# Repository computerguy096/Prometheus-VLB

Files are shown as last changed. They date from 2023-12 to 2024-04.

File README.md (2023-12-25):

# Prometheus VLB - an affordable way to get a fast video card for your VLB systems

This is an open source video card, designed to be used in systems with a VLB slot, like a 486 class machine. It's designed around the S3 Trio64V+ video chip (86C765), which can be found in many PCI video cards, as wel as separately.
As a bonus, this particular chip allows for a very easy implementation for the VL bus, with almost no support components required, even the RAMDAC is built into the chip.
The card was designed from scratch, using only the official datasheet and photos of an STB Powergraph 64 for a few visual references.

Prometheus VLB rev 1A PCBs

## Features

- S3 Trio64V+ (86C765) or S3 ViRGE (86C325)[^1] video chip, with a powerful and very compatible 2D core, perfect for most DOS games
- up to 2MB of fast page or EDO memory, with clearance for SOJ sockets
- configurable address range, with 32MB, 64MB and 1024MB as options
- simple design, built in RAMDAC, only requires a few extra parts
- fully configurable registers with pull-downs, allowing the tuning of various parameters like memory timings, etc.
- flexible EEPROM implementation, allows DIP28, DIP32, as well as PLCC32 footprints
- common VGA connector placement, allows reusability for many of the old metallic brackets
- small PCB, which does not extend below the card edge in the front, so it will not collide with keyboard controller chips on some boards

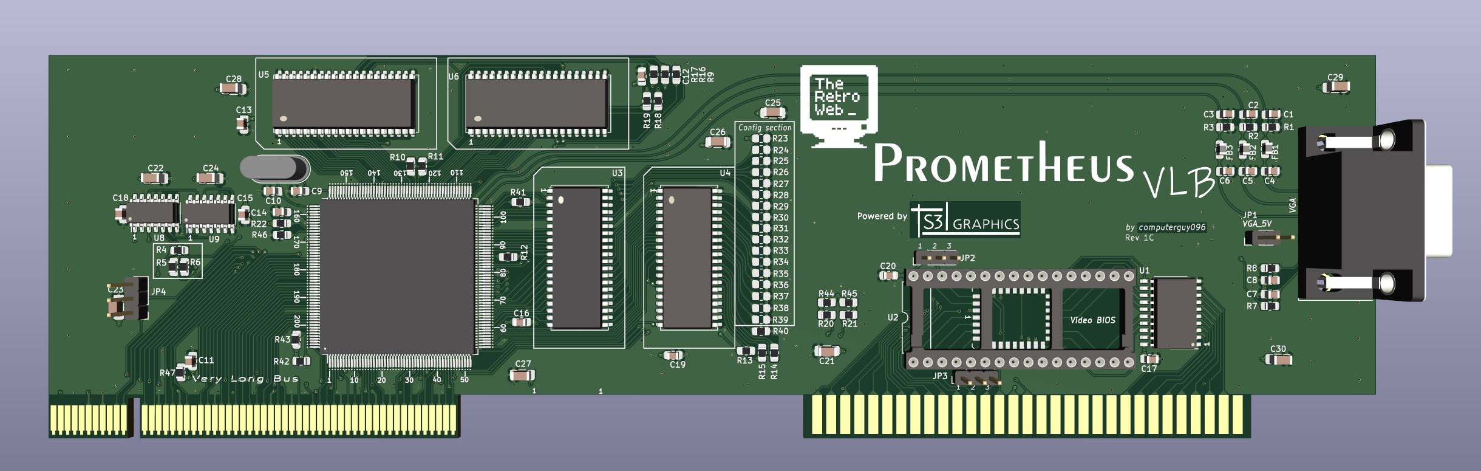
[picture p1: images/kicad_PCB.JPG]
Prometheus VLB rev 1B rendered PCB


## Documentation

Trio64V+ datasheet can be read [here](docs/DB018-A_Trio64V+_Integrated_Graphics_Video_Accelerator_Jul95.pdf), and the ViRGE datasheet [here](docs/DB019-B_ViRGE_Integrated_3D_Accelerator_Aug1996.pdf).

## FAQ

**Q: Is this for sale? Where can I buy one?**

> Nope, it's not for sale, and I do not have any intentions to sell them. However, I am an advocate for open source hardware so the design is fully public (the gerbers, the schematic, everything, all provided under GPLv3) so you can build your own card freely.

**Q: What parts do I need to build a card?**

> There is a [CSV BOM](kicad/virge-vlb.csv) included, as well as an [interactive HTML BOM](kicad/bom/ibom.html), with all the parts and their quantities listed. The main thing to acquire is the S3 chip itself, which can be salvaged from PCI cards or bought as NOS trays. 
**Be careful with the chip model, only 86C765 and 86C325 are fully pin compatible and will work!**

**Q: What about the video BIOS?**

> The binary is from an STB Powergraph64 (closest card to this one in terms of design) and it is available in the repository right [here](VBIOS.BIN)

**Q: Where can i find the gerber files?**

> At `/kicad/gerber` on this repo.

## Footnotes

[^1]: S3 ViRGE support is experimental in VLB mode, since there are no drivers available for it.

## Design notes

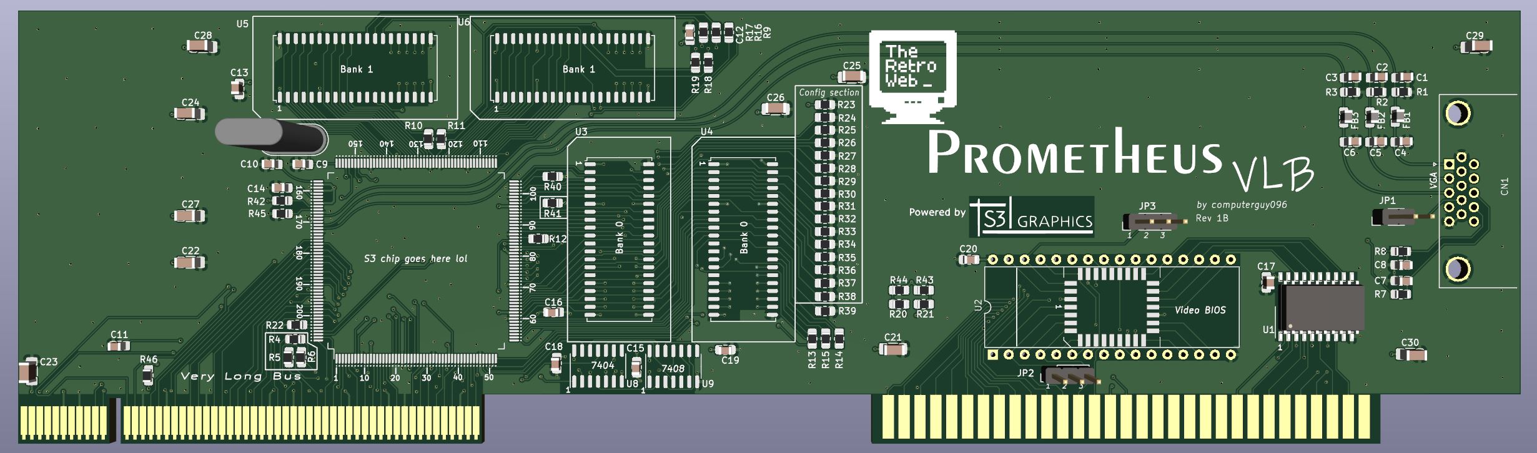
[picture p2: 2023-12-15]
images/rev1B.JPG

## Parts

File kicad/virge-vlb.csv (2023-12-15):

Component Count: | 93
Collated Components:
Item | Qty | Reference(s) | Value | LibPart | Footprint | Datasheet | DNP | Function | Installed | License | manf#
1 | 10 | C1, C2, C3, C4, C5, C6, C7, C8, C9, C10 | 10pF | Device:C | Capacitor_SMD:C_0805_2012Metric_Pad1.18x1.45mm_HandSolder | ~
2 | 1 | C11 | 100pF | Device:C | Capacitor_SMD:C_0805_2012Metric_Pad1.18x1.45mm_HandSolder | ~
3 | 9 | C12, C13, C14, C15, C16, C17, C18, C19, C20 | 100nF | Device:C | Capacitor_SMD:C_0805_2012Metric_Pad1.18x1.45mm_HandSolder | ~
4 | 10 | C21, C22, C23, C24, C25, C26, C27, C28, C29, C30 | 10uF | Device:C_Polarized | Capacitor_SMD:C_1206_3216Metric_Pad1.33x1.80mm_HandSolder | ~
5 | 1 | CN1 | VGA | Connector:DE15_Plug_HighDensity | VLB:DSUB-15_female | ~
6 | 3 | FB1, FB2, FB3 | FerriteBead | Device:FerriteBead | Inductor_SMD:L_0805_2012Metric_Pad1.15x1.40mm_HandSolder | ~
7 | 1 | JP1 | Conn_01x02 | Connector_Generic:Conn_01x02 | Connector_PinHeader_2.54mm:PinHeader_1x02_P2.54mm_Vertical | ~ |  | SPI Power DDC/i2c ROM
8 | 2 | JP2, JP3 | Conn_01x03 | Connector_Generic:Conn_01x03 | Connector_PinHeader_2.54mm:PinHeader_1x03_P2.54mm_Vertical | ~
9 | 15 | R1, R2, R9, R10, R11, R12, R13, R14, R15, R16, R17, R18, R19, R20, R21 | 33R | Device:R | Resistor_SMD:R_0805_2012Metric_Pad1.20x1.40mm_HandSolder | ~
10 | 3 | R3, R4, R5 | 75R | Device:R | Resistor_SMD:R_0805_2012Metric_Pad1.20x1.40mm_HandSolder | ~
11 | 3 | R6, R7, R8 | 0R | Device:R | Resistor_SMD:R_0805_2012Metric_Pad1.20x1.40mm_HandSolder | ~
12 | 23 | R22, R23, R24, R25, R26, R27, R28, R29, R30, R31, R32, R33, R34, R35, R36, R37, R38, R39, R40, R41, R42, R43, R44 | 10K | Device:R | Resistor_SMD:R_0805_2012Metric_Pad1.20x1.40mm_HandSolder | ~ |  |  | 1
13 | 2 | R45, R46 | 150R | Device:R | Resistor_SMD:R_0805_2012Metric_Pad1.20x1.40mm_HandSolder | ~
14 | 1 | U1 | 74LS244 | 74xx:74LS244 | Package_SO:SO-20_12.8x7.5mm_P1.27mm | http://www.ti.com/lit/ds/symlink/sn74ls244.pdf
15 | 1 | U2 | 27C020 | Memory_EPROM:27C020 | VLB:EEPROM_combo | http://ww1.microchip.com/downloads/en/devicedoc/doc0570.pdf
16 | 4 | U3, U4, U5, U6 | V53C16258H | :HY51V18164B_1 | VLB:SOJ-40_10.16x26.00mm_P1.27mm
17 | 1 | U7 | 86C325 | virge:86C375 | VLB:QFP-208 |  |  |  |  | 86C375 VL Bus | 86C375
18 | 1 | U8 | 7404 | 74xx:74HC04 | Package_SO:SO-14_3.9x8.65mm_P1.27mm | https://assets.nexperia.com/documents/data-sheet/74HC_HCT04.pdf
19 | 1 | U9 | 7408 | 74xx_IEEE:7408 | Package_SO:SO-14_3.9x8.65mm_P1.27mm
20 | 1 | Y1 | 14.318MHz | Device:Crystal | Crystal:Crystal_HC18-U_Vertical | ~

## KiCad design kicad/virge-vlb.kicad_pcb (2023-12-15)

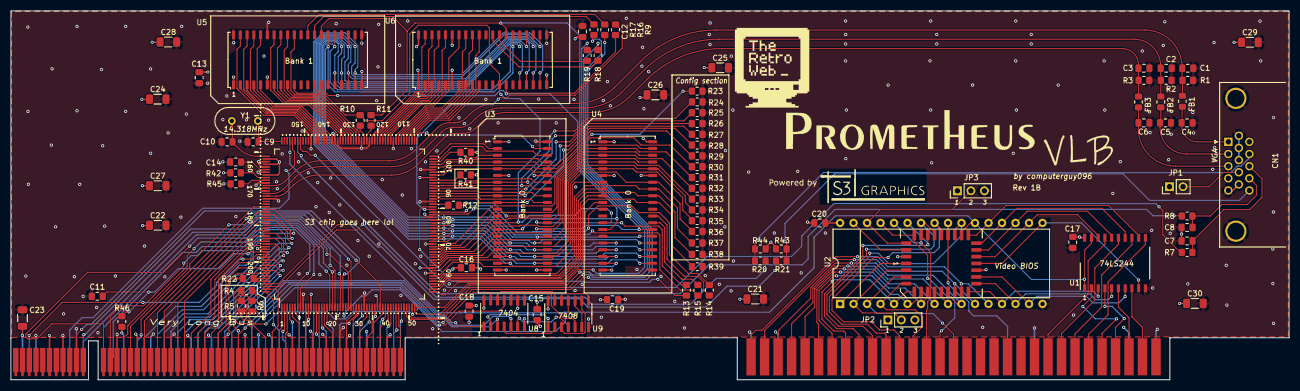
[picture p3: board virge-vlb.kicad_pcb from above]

Board: 4 copper layers, 240.5 x 69.4 mm, 94 parts (0 on the bottom side), 239 nets.

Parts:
C1, C2, C3, C4, C5, C6, C7, C8, C9, C10: 10pF; C_0805_2012Metric_Pad1.18x1.45mm_HandSolder
C11: 100pF; C_0805_2012Metric_Pad1.18x1.45mm_HandSolder
C12, C13, C14, C15, C16, C17, C18, C19, C20: 100nF; C_0805_2012Metric_Pad1.18x1.45mm_HandSolder
C21, C22, C23, C24, C25, C26, C27, C28, C29, C30: 10uF; C_1206_3216Metric_Pad1.33x1.80mm_HandSolder
CN1: VGA; DSUB-15_female
FB1, FB2, FB3: FerriteBead; L_0805_2012Metric_Pad1.15x1.40mm_HandSolder
J1: VLB_slot; BUS_VLB_Board
JP1: Conn_01x02; PinHeader_1x02_P2.54mm_Vertical
JP2, JP3: Conn_01x03; PinHeader_1x03_P2.54mm_Vertical
R1, R2, R3: 75R; R_0805_2012Metric_Pad1.20x1.40mm_HandSolder
R4, R5, R6: 0R; R_0805_2012Metric_Pad1.20x1.40mm_HandSolder
R7, R8, R9, R10, R11, R12, R13, R14, R15, R16, R17, R18, R19, R20, R21: 33R; R_0805_2012Metric_Pad1.20x1.40mm_HandSolder
R22, R23, R24, R25, R26, R27, R28, R29, R30, R31, R32, R33, R34, R35, R36, R37, R38, R39, R40, R41, R42, R43, R44: 10K; R_0805_2012Metric_Pad1.20x1.40mm_HandSolder
R45, R46: 150R; R_0805_2012Metric_Pad1.20x1.40mm_HandSolder
U1: 74LS244; SO-20_12.8x7.5mm_P1.27mm
U2: 27C020; EEPROM_combo
U3, U4, U5, U6: V53C16258H; SOJ-40_10.16x26.00mm_P1.27mm
U7: 86C325; QFP-208
U8: 7404; SO-14_3.9x8.65mm_P1.27mm
U9: 7408; SO-14_3.9x8.65mm_P1.27mm
Y1: 14.318MHz; Crystal_HC18-U_Vertical

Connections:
/BLUE: C6.1, CN1.3, FB3.1
/DDC_SCL: R21.1, U7.205 (SPCLK/ESYNC)
/DDC_SDA: R20.1, U7.206 (SPD/~BLANK)
/GREEN: C5.1, CN1.2, FB2.1
/HS: R7.1, U7.149 (HSYNC)
/HS_VGA: C7.1, CN1.13, R7.2
/ISA Bus/ISA_D0: J1.C40 (DB0), U1.17 (I3b)
/ISA Bus/ISA_D1: J1.C39 (DB1), U1.15 (I2b)
/ISA Bus/ISA_D2: J1.C38 (DB2), U1.13 (I1b)
/ISA Bus/ISA_D3: J1.C37 (DB3), U1.11 (I0b)
/ISA Bus/ISA_D4: J1.C36 (DB4), U1.2 (I0a)
/ISA Bus/ISA_D5: J1.C35 (DB5), U1.4 (I1a)
/ISA Bus/ISA_D6: J1.C34 (DB6), U1.6 (I2a)
/ISA Bus/ISA_D7: J1.C33 (DB7), U1.8 (I3a)
/ISA Bus/R_A0: J1.C62 (BA00), U2.12 (A0)
/ISA Bus/R_A1: J1.C61 (BA01), U2.11 (A1)
/ISA Bus/R_A2: J1.C60 (BA02), U2.10 (A2)
/ISA Bus/R_A3: J1.C59 (BA03), U2.9 (A3)
/ISA Bus/R_A4: J1.C58 (BA04), U2.8 (A4)
/ISA Bus/R_A5: J1.C57 (BA05), U2.7 (A5)
/ISA Bus/R_A6: J1.C56 (BA06), U2.6 (A6)
/ISA Bus/R_A7: J1.C55 (BA07), U2.5 (A7)
/ISA Bus/R_A8: J1.C54 (BA08), U2.27 (A8)
/ISA Bus/R_A9: J1.C53 (BA09), U2.26 (A9)
/ISA Bus/R_A10: J1.C52 (BA10), U2.23 (A10)
/ISA Bus/R_A11: J1.C51 (BA11), U2.25 (A11)
/ISA Bus/R_A12: J1.C50 (BA12), U2.4 (A12)
/ISA Bus/R_A13: J1.C49 (BA13), U2.28 (A13)
/ISA Bus/R_A14: J1.C48 (BA14), U2.29 (A14)
/ISA Bus/R_A15: J1.C47 (BA15), U2.3 (A15)
/ISA Bus/R_D0: U1.3 (O3b), U2.13 (D0)
/ISA Bus/R_D1: U1.5 (O2b), U2.14 (D1)
/ISA Bus/R_D2: U1.7 (O1b), U2.15 (D2)
/ISA Bus/R_D3: U1.9 (O0b), U2.17 (D3)
/ISA Bus/R_D4: U1.18 (O0a), U2.18 (D4)
/ISA Bus/R_D5: U1.16 (O1a), U2.19 (D5)
/ISA Bus/R_D6: U1.14 (O2a), U2.20 (D6)
/ISA Bus/R_D7: U1.12 (O3a), U2.21 (D7)
/ISA Bus/SMEMR: J1.C12 (~SMEMR), U2.24 (~OE)
/Memory Bus/CAS0: R12.2, U3.29 (~LCAS)
/Memory Bus/CAS1: R13.2, U3.28 (~UCAS)
/Memory Bus/CAS2: R14.2, U4.29 (~LCAS)
/Memory Bus/CAS3: R15.2, U4.28 (~UCAS)
/Memory Bus/CAS4: R16.2, U5.29 (~LCAS)
/Memory Bus/CAS5: R17.2, U5.28 (~UCAS)
/Memory Bus/CAS6: R18.2, U6.29 (~LCAS)
/Memory Bus/CAS7: R19.2, U6.28 (~UCAS)
/Memory Bus/MA0: U3.16 (A0), U4.16 (A0), U5.16 (A0), U6.16 (A0), U7.79 (MA0)
/Memory Bus/MA1: U3.17 (A1), U4.17 (A1), U5.17 (A1), U6.17 (A1), U7.77 (MA1)
/Memory Bus/MA2: U3.18 (A2), U4.18 (A2), U5.18 (A2), U6.18 (A2), U7.75 (MA2)
/Memory Bus/MA3: U3.19 (A3), U4.19 (A3), U5.19 (A3), U6.19 (A3), U7.73 (MA3)
/Memory Bus/MA4: U3.22 (A4), U4.22 (A4), U5.22 (A4), U6.22 (A4), U7.72 (MA4)
/Memory Bus/MA5: U3.23 (A5), U4.23 (A5), U5.23 (A5), U6.23 (A5), U7.74 (MA5)
/Memory Bus/MA6: U3.24 (A6), U4.24 (A6), U5.24 (A6), U6.24 (A6), U7.76 (MA6)
/Memory Bus/MA7: U3.25 (A7), U4.25 (A7), U5.25 (A7), U6.25 (A7), U7.78 (MA7)
/Memory Bus/MA8: U3.26 (A8), U4.26 (A8), U5.26 (A8), U6.26 (A8), U7.80 (MA8)
/Memory Bus/OE: R11.2, U3.27 (OE), U4.27 (OE), U5.27 (OE), U6.27 (OE)
/Memory Bus/PD0: U3.2 (DQ0), U7.104 (PD0)
/Memory Bus/PD1: R40.2, U3.3 (DQ1), U7.102 (PD1)
/Memory Bus/PD2: R29.2, U3.4 (DQ2), U7.100 (PD2)
/Memory Bus/PD3: R30.2, U3.5 (DQ3), U7.97 (PD3)
/Memory Bus/PD4: R25.2, U3.7 (DQ4), U7.94 (PD4)
/Memory Bus/PD5: R26.2, U3.8 (DQ5), U7.92 (PD5)
/Memory Bus/PD6: R27.2, U3.9 (DQ6), U7.90 (PD6)
/Memory Bus/PD7: R28.2, U3.10 (DQ7), U7.88 (PD7)
/Memory Bus/PD8: U3.31 (DQ8), U7.89 (PD8)
/Memory Bus/PD9: U3.32 (DQ9), U7.91 (PD9)
/Memory Bus/PD10: R24.2, U3.33 (DQ10), U7.93 (PD10)
/Memory Bus/PD11: R41.2, U3.34 (DQ11), U7.95 (PD11)
/Memory Bus/PD12: R23.2, U3.36 (DQ12), U7.98 (PD12)
/Memory Bus/PD13: U3.37 (DQ13), U7.101 (PD13)
/Memory Bus/PD14: U3.38 (DQ14), U7.103 (PD14)
/Memory Bus/PD15: U3.39 (DQ15), U7.105 (PD15)
/Memory Bus/PD16: R31.2, U4.2 (DQ0), U7.69 (PD16)
/Memory Bus/PD17: R32.2, U4.3 (DQ1), U7.67 (PD17)
/Memory Bus/PD18: R33.2, U4.4 (DQ2), U7.65 (PD18)
/Memory Bus/PD19: R35.2, U4.5 (DQ3), U7.63 (PD19)
/Memory Bus/PD20: U4.7 (DQ4), U7.59 (PD20)
/Memory Bus/PD21: U4.8 (DQ5), U7.57 (PD21)
/Memory Bus/PD22: U4.9 (DQ6), U7.55 (PD22)
/Memory Bus/PD23: U4.10 (DQ7), U7.53 (PD23)
/Memory Bus/PD24: R39.2, U4.31 (DQ8), U7.54 (PD24)
/Memory Bus/PD25: R38.2, U4.32 (DQ9), U7.56 (PD25)
/Memory Bus/PD26: R37.2, U4.33 (DQ10), U7.58 (PD26)
/Memory Bus/PD27: R36.2, U4.34 (DQ11), U7.61 (PD27)
/Memory Bus/PD28: R34.2, U4.36 (DQ12), U7.64 (PD28)
/Memory Bus/PD29: U4.37 (DQ13), U7.66 (PD29)
/Memory Bus/PD30: U4.38 (DQ14), U7.68 (PD30)
/Memory Bus/PD31: U4.39 (DQ15), U7.70 (PD31)
/Memory Bus/PD32: U5.2 (DQ0), U7.143 (PD32)
/Memory Bus/PD33: U5.3 (DQ1), U7.141 (PD33)
/Memory Bus/PD34: U5.4 (DQ2), U7.139 (PD34)
/Memory Bus/PD35: U5.5 (DQ3), U7.136 (PD35)
/Memory Bus/PD36: U5.7 (DQ4), U7.133 (PD36)
/Memory Bus/PD37: U5.8 (DQ5), U7.131 (PD37)
/Memory Bus/PD38: U5.9 (DQ6), U7.129 (PD38)
/Memory Bus/PD39: U5.10 (DQ7), U7.127 (PD39)
/Memory Bus/PD40: U5.31 (DQ8), U7.128 (PD40)
/Memory Bus/PD41: U5.32 (DQ9), U7.130 (PD41)
/Memory Bus/PD42: U5.33 (DQ10), U7.132 (PD42)
/Memory Bus/PD43: U5.34 (DQ11), U7.134 (PD43)
/Memory Bus/PD44: U5.36 (DQ12), U7.138 (PD44)
/Memory Bus/PD45: U5.37 (DQ13), U7.140 (PD45)
/Memory Bus/PD46: U5.38 (DQ14), U7.142 (PD46)
/Memory Bus/PD47: U5.39 (DQ15), U7.144 (PD47)
/Memory Bus/PD48: U6.2 (DQ0), U7.121 (PD48)
/Memory Bus/PD49: U6.3 (DQ1), U7.119 (PD49)
/Memory Bus/PD50: U6.4 (DQ2), U7.117 (PD50)
/Memory Bus/PD51: U6.5 (DQ3), U7.115 (PD51)
/Memory Bus/PD52: U6.7 (DQ4), U7.112 (PD52)
/Memory Bus/PD53: U6.8 (DQ5), U7.110 (PD53)
/Memory Bus/PD54: U6.9 (DQ6), U7.108 (PD54)
/Memory Bus/PD55: U6.10 (DQ7), U7.106 (VCLKI/PD55)
/Memory Bus/PD56: U6.31 (DQ8), U7.107 (PD56)
/Memory Bus/PD57: U6.32 (DQ9), U7.109 (PD57)
/Memory Bus/PD58: U6.33 (DQ10), U7.111 (PD58)
/Memory Bus/PD59: U6.34 (DQ11), U7.113 (PD59)
/Memory Bus/PD60: U6.36 (DQ12), U7.116 (PD60)
/Memory Bus/PD61: U6.37 (DQ13), U7.118 (PD61)
/Memory Bus/PD62: U6.38 (DQ14), U7.120 (PD62)
/Memory Bus/PD63: U6.39 (DQ15), U7.122 (PD63)
/Memory Bus/RAS: R9.2, U3.14 (~RAS), U4.14 (~RAS), U5.14 (~RAS), U6.14 (~RAS)
/Memory Bus/WE: R10.2, U3.13 (~WE), U4.13 (~WE), U5.13 (~WE), U6.13 (~WE)
/RED: C4.1, CN1.1, FB1.1
/S3_BLUE: C3.1, FB3.2, R3.1, U7.172 (AB)
/S3_GREEN: C2.1, FB2.2, R2.1, U7.171 (AG)
/S3_RED: C1.1, FB1.2, R1.1, U7.168 (AR)
/VL Bus/ADS: J1.A45 (ADS), U7.20 (~SADS)
/VL Bus/BE0: J1.A39 (BE0), U7.38 (~SBE0)
/VL Bus/BE1: J1.A41 (BE1), U7.27 (~SBE1)
/VL Bus/BE2: J1.A42 (BE2), U7.19 (~SBE2)
/VL Bus/BE3: J1.A44 (BE3), U7.7 (~SBE3)
/VL Bus/IRQ9: J1.B50 (IRQ9), U7.152 (SINTR)
/VL Bus/LCLK: J1.B56 (LCLK), U7.194 (SCLK)
/VL Bus/LDEV: J1.A49 (LDEV), U7.24 (~LOCA)
/VL Bus/LRDY: J1.A48 (LRDY), U7.23 (~SRDY)
/VL Bus/M/IO: J1.B44 (M/IO), U7.8 (SM/~IO)
/VL Bus/RDYR: J1.B48 (RDYRTN), U7.21 (~RDYIN)
/VL Bus/RST: J1.B42 (~RESET), R46.2
/VL Bus/SAUP1: U7.25 (SAUP1), U9.11
/VL Bus/SAUP2: R5.2, U7.50 (SAUP2)
/VL Bus/VL_A2: J1.B40 (A2), U7.176 (SA2)
/VL Bus/VL_A3: J1.B39 (A3), U7.177 (SA3)
/VL Bus/VL_A4: J1.A37 (A4), U7.178 (SA4)
/VL Bus/VL_A5: J1.B37 (A5), U7.179 (SA5)
/VL Bus/VL_A6: J1.A36 (A6), U7.180 (SA6)
/VL Bus/VL_A7: J1.B36 (A7), U7.181 (SA7)
/VL Bus/VL_A8: J1.A34 (A8), U7.182 (SA8)
/VL Bus/VL_A9: J1.B35 (A9), U7.183 (SA9)
/VL Bus/VL_A10: J1.A33 (A10), U7.185 (SA10)
/VL Bus/VL_A11: J1.B34 (A11), U7.186 (SA11)
/VL Bus/VL_A12: J1.A32 (A12), U7.187 (SA12)
/VL Bus/VL_A13: J1.B33 (A13), U7.188 (SA13)
/VL Bus/VL_A14: J1.A31 (A14), U7.189 (SA14)
/VL Bus/VL_A15: J1.B31 (A15), U7.190 (SA15)
/VL Bus/VL_A16: J1.A30 (A16), U7.191 (SA16)
/VL Bus/VL_A17: J1.B30 (A17), U7.196 (SA17)
/VL Bus/VL_A18: J1.A29 (A18), U7.197 (SA18)
/VL Bus/VL_A19: J1.B28 (A19), U7.198 (SA19)
/VL Bus/VL_A20: J1.A28 (A20), U7.199 (SA20)
/VL Bus/VL_A21: J1.B27 (A21), U7.200 (SA21)
/VL Bus/VL_A22: J1.A26 (A22), U7.201 (SA22)
/VL Bus/VL_A23: J1.B26 (A23), U8.1
/VL Bus/VL_A23+A24: U9.3, U9.9
/VL Bus/VL_A23-A26: U9.8, U9.12
/VL Bus/VL_A23_O: U8.2, U9.1
/VL Bus/VL_A24: J1.A25 (A24), U8.3
/VL Bus/VL_A24_O: U8.4, U9.2
/VL Bus/VL_A25: J1.B25 (A25), R4.2
/VL Bus/VL_A25+A26: U9.6, U9.10
/VL Bus/VL_A25_O: U8.6, U9.4
/VL Bus/VL_A26: J1.A23 (A26), R6.2
/VL Bus/VL_A26_O: U8.10, U9.5
/VL Bus/VL_A29: J1.B23 (A29), U8.13
/VL Bus/VL_A29_O: U8.12, U9.13
/VL Bus/VL_A30: J1.A21 (A30), R5.1
/VL Bus/VL_D0: J1.B1 (D0), U7.46 (SD0)
/VL Bus/VL_D1: J1.A1 (D1), U7.45 (SD1)
/VL Bus/VL_D2: J1.B2 (D2), U7.44 (SD2)
/VL Bus/VL_D3: J1.A2 (D3), U7.43 (SD3)
/VL Bus/VL_D4: J1.B3 (D4), U7.42 (SD4)
/VL Bus/VL_D5: J1.A4 (D5), U7.41 (SD5)
/VL Bus/VL_D6: J1.B4 (D6), U7.40 (SD6)
/VL Bus/VL_D7: J1.A5 (D7), U7.39 (SD7)
/VL Bus/VL_D8: J1.B5 (D8), U7.36 (SD8)
/VL Bus/VL_D9: J1.A6 (D9), U7.35 (SD9)
/VL Bus/VL_D10: J1.B7 (D10), U7.34 (SD10)
/VL Bus/VL_D11: J1.A7 (D11), U7.33 (SD11)
/VL Bus/VL_D12: J1.B8 (D12), U7.31 (SD12)
/VL Bus/VL_D13: J1.A8 (D13), U7.30 (SD13)
/VL Bus/VL_D14: J1.B10 (D14), U7.29 (SD14)
/VL Bus/VL_D15: J1.A9 (D15), U7.28 (SD15)
/VL Bus/VL_D16: J1.B11 (D16), U7.18 (SD16)
/VL Bus/VL_D17: J1.A11 (D17), U7.17 (SD17)
/VL Bus/VL_D18: J1.B12 (D18), U7.16 (SD18)
/VL Bus/VL_D19: J1.A13 (D19), U7.15 (SD19)
/VL Bus/VL_D20: J1.B13 (D20), U7.14 (SD20)
/VL Bus/VL_D21: J1.A14 (D21), U7.13 (SD21)
/VL Bus/VL_D22: J1.B15 (D22), U7.11 (SD22)
/VL Bus/VL_D23: J1.A15 (D23), U7.10 (SD23)
/VL Bus/VL_D24: J1.B16 (D24), U7.6 (SD24)
/VL Bus/VL_D25: J1.A16 (D25), U7.5 (SD25)
/VL Bus/VL_D26: J1.B17 (D26), U7.4 (SD26)
/VL Bus/VL_D27: J1.A18 (D27), U7.3 (SD27)
/VL Bus/VL_D28: J1.B18 (D28), U7.2 (SD28)
/VL Bus/VL_D29: J1.A19 (D29), U7.1 (SD29)
/VL Bus/VL_D30: J1.B19 (D30), U7.208 (SD30)
/VL Bus/VL_D31: J1.A20 (D31), U7.207 (SD31)
/VL Bus/W/R: J1.B45 (W/R), U7.26 (SW/~R)
/VS: R8.1, U7.150 (VSYNC)
/VS_VGA: C8.1, CN1.14, R8.2
GND: C1.2, C2.2, C3.2, C4.2, C5.2, C6.2, C7.2, C8.2, C9.1, C10.1, C11.2, C12.1, C13.2, C14.2, C15.2, C16.2, C17.2, C18.2, C19.2, C20.1, C21.2, C22.2, C23.2, C24.2, C25.2, C26.2, C27.2, C28.2, C29.2, C30.2, CN1.5, CN1.6, CN1.7, CN1.8, CN1.10, J1.A3 (VSS), J1.A10 (VSS), J1.A17 (VSS), J1.A24 (VSS), J1.A35 (VSS), J1.A43 (VSS), J1.A51 (VSS), J1.B6 (VSS), J1.B14 (VSS), J1.B22 (VSS), J1.B29 (VSS), J1.B38 (VSS), J1.B49 (VSS), J1.B55 (VSS), J1.C1 (GND), J1.C10 (GND), J1.C31 (GND), JP2.3, JP3.3, R1.2, R2.2, R3.2, R23.1, R24.1, R25.1, R26.1, R27.1, R28.1, R29.1, R30.1, R31.1, R32.1, R33.1, R34.1, R35.1, R36.1, R37.1, R38.1, R39.1, R40.1, R41.1, R45.1, U1.10 (GND), U2.16 (GND), U3.21 (VSS), U3.35 (VSS), U3.40 (VSS), U4.21 (VSS), U4.35 (VSS), U4.40 (VSS), U5.21 (VSS), U5.35 (VSS), U5.40 (VSS), U6.21 (VSS), U6.35 (VSS), U6.40 (VSS), U7.9 (VSS), U7.22 (VSS), U7.32 (VSS), U7.47 (VSS), U7.60 (VSS), U7.71 (VSS), U7.87 (VSS), U7.99 (VSS), U7.114 (VSS), U7.123 (VSS), U7.126 (VSS), U7.135 (VSS), U7.145 (VSS), U7.159 (AVSS), U7.161 (AVSS), U7.163 (AVSS), U7.167 (AVSS), U7.173 (AVSS), U7.195 (VSS), U8.7 (GND), U9.7 (GND)
unnamed: CN1.12, R20.2, R44.2
unnamed: CN1.15, R21.2, R43.2
unnamed: CN1.9, JP1.2
unnamed: JP2.2, U2.2 (A16)
unnamed: JP3.2, U2.30 (A17)
unnamed: R4.1, U8.5
unnamed: R6.1, U8.11
unnamed: R12.1, U7.86 (~CAS0)
unnamed: R13.1, U7.85 (~CAS1)
unnamed: R14.1, U7.83 (~CAS2)
unnamed: R15.1, U7.82 (~CAS3)
unnamed: R16.1, U7.48 (~CAS4)
unnamed: R17.1, U7.49 (~CAS5)
unnamed: R18.1, U7.51 (~CAS6)
unnamed: R19.1, U7.52 (~CAS7)
unnamed: R11.1, U7.124 (~OE)
unnamed: R9.1, U7.84 (~RAS0)
unnamed: R10.1, U7.125 (~WE)
unnamed: C11.1, R46.1, U7.193 (~SRESET)
unnamed: R45.2, U7.166 (RSET)
unnamed: C14.1, U7.162 (VREF)
unnamed: C9.2, U7.156 (XIN), Y1.2
unnamed: C10.2, U7.157 (XOUT), Y1.1
unnamed: R22.1, U7.203 (~VREQ/VRDY/EVIDEO), U7.204 (~CREQ/CRDY/EVCLK)
unnamed: R42.1, U7.165 (~PDOWN)
ROMCS: U1.1 (OEa), U1.19 (OEb), U2.22 (~CE), U7.153 (~ROMCS/GOP1)
VCC: C12.2, C13.1, C15.1, C16.1, C17.1, C18.1, C19.1, C20.2, C21.1, C22.1, C23.1, C24.1, C25.1, C26.1, C27.1, C28.1, C29.1, C30.1, J1.A12 (VCC), J1.A27 (VCC), J1.A40 (VCC), J1.A53 (VCC), J1.B9 (VCC), J1.B20 (VCC), J1.B32 (VCC), J1.B57 (VCC), J1.C3 (VCC), J1.C29 (VCC), JP1.1, JP2.1, JP3.1, R22.2, R42.2, R43.1, R44.1, U1.20 (VCC), U2.32 (VCC), U3.1 (VCC), U3.6 (VCC), U3.20 (VCC), U4.1 (VCC), U4.6 (VCC), U4.20 (VCC), U5.1 (VCC), U5.6 (VCC), U5.20 (VCC), U6.1 (VCC), U6.6 (VCC), U6.20 (VCC), U7.12 (VDD), U7.37 (VDD), U7.62 (VDD), U7.81 (VDD), U7.96 (VDD), U7.137 (VDD), U7.158 (CLKAVDD1), U7.160 (CLKAVDD2), U7.164 (AVDD), U7.169 (AVDD), U7.170 (AVDD), U7.192 (VDD), U8.9, U8.14 (VCC), U9.14 (VCC)

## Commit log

2023-06-06 work on the memory bus, fixed symbols
    [address.kicad_sch, busctrl.kicad_sch, data.kicad_sch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]
2023-06-07 changed memory chips, more progress
    [address.kicad_sch, busctrl.kicad_sch, data.kicad_sch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]
2023-06-08 PCB work
    [busctrl.kicad_sch, data.kicad_sch, virge-vlb.kicad_pcb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]
2023-06-09 even more PCB work
    [address.kicad_sch, data.kicad_sch, virge-vlb.kicad_pcb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]
2023-06-09 added VREF R for fine tuning
    [virge-vlb.kicad_sch]
2023-06-09 added register strap resistors
    [data.kicad_sch, virge-vlb.kicad_pcb]
2023-06-10 initial PCB routed
    [address.kicad_sch, busctrl.kicad_sch, virge-vlb.kicad_pcb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]
2023-06-30 added SAUP decoding, adjusted VGA conn.
    [address.kicad_sch, busctrl.kicad_sch, data.kicad_sch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]
2023-07-04 added ground vias, polished silkscreen
    [virge-vlb.kicad_pcb]
2023-07-04 added address jumpers
    [address.kicad_sch, virge-vlb.kicad_pcb, virge-vlb.kicad_sch]
2023-07-05 final touches
    [virge-vlb-B_Mask.gbr, virge-vlb-B_Paste.gbr, virge-vlb-B_Silkscreen.gbr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]
2023-07-06 Board review changes 2023-07-06
    [address.kicad_sch, busctrl.kicad_sch, data.kicad_sch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]
2023-07-06 fixed some clearance issues, fixed S3 logo, fixed annotations
    [address.kicad_sch, busctrl.kicad_sch, data.kicad_sch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]
2023-07-13 final changes for revision 1A
    [address.kicad_sch, data.kicad_sch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]
2023-07-25 critical fixes for rev 1B
    [address.kicad_sch, busctrl.kicad_sch, data.kicad_sch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]
2023-12-04 changed QFP and ROM footprint
    [address.kicad_sch, busctrl.kicad_sch, data.kicad_sch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]
2023-12-05 added pull up for VREQ
    [virge-vlb.kicad_pcb, virge-vlb.kicad_sch]
2023-12-05 some polishing
    [busctrl.kicad_sch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]
2023-12-05 apparently its case sensitive
2023-12-05 yep, it was case sensitive, d'oh
2023-12-08 some improvements here and there
    [address.kicad_sch, busctrl.kicad_sch, virge-vlb.kicad_pcb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]
2023-12-11 added vbios
    [virge-vlb.kicad_pcb]
2023-12-14 some optimizations and silkscreen updating
    [address.kicad_sch, busctrl.kicad_sch, data.kicad_sch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]
2023-12-15 some tweaks
    [virge-vlb.kicad_pcb]
2023-12-15 some final tweaks
    [address.kicad_sch, busctrl.kicad_sch, data.kicad_sch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]
2023-12-15 typo fix
    [virge-vlb-B_Mask.gbr, virge-vlb-B_Paste.gbr, virge-vlb-B_Silkscreen.gbr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]
2023-12-21 rounded traces + teardrops
2023-12-25 added pull up, new BOM
    [address.kicad_sch, busctrl.kicad_sch, data.kicad_sch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]
2023-12-25 updated bom and gerber
    [virge-vlb-B_Mask.gbr, virge-vlb-B_Paste.gbr, virge-vlb-B_Silkscreen.gbr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]
2024-04-06 many fixes for rev 1C
    [busctrl.kicad_sch, virge-vlb.csv, virge-vlb.kicad_sch]
2024-04-06 updated VLB footprint
    [address.kicad_sch, busctrl.kicad_sch, data.kicad_sch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]
2024-04-06 fixed VGA footprint
    [address.kicad_sch, busctrl.kicad_sch, data.kicad_sch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]
2024-04-06 archived 1B gerber
    [virge-vlb-B_Mask.gbr, virge-vlb-B_Paste.gbr, virge-vlb-B_Silkscreen.gbr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]
2024-04-06 enlarged SOJ pads
    [virge-vlb.kicad_pcb]
2024-04-06 final fixes
    [address.kicad_sch, busctrl.kicad_sch, virge-vlb.kicad_pcb]
2024-04-07 added gerbers and teardrops, trace optimizations
    [virge-vlb-B_Mask.gbr, virge-vlb-B_Paste.gbr, virge-vlb-B_Silkscreen.gbr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]
2024-04-13 fix for LS245 bus conflict
    [address.kicad_sch, busctrl.kicad_sch, data.kicad_sch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]
2025-03-18 updated to kicad 9
    [address.kicad_sch, busctrl.kicad_sch, data.kicad_sch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]

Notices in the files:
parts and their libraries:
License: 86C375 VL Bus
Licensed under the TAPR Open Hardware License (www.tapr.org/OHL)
